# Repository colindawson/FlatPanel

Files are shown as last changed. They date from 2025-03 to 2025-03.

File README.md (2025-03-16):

# Remote FlatPanel to help with taking calibration frames.

This flat panel is going to be an open source, dimmable flat panel for astronomy.

## Features
- Dimmable flat panel
- Optional dew heater
- Flat panel acts like lens cap
- AsiAir remote controlable (both for heater and panel)
- oLed display for local control
- Wifi remote control
- Ascom Alpaca control
- Temperature and humidity sensor
- Fully automatic mode for dew heater

Above is the fully list of features that I'm planning.  Some of the features will cancel out other features. For example Fully Automatic mode will be available for the dew heater, to use the minimum power so that it keeps away dew without human interaction, however I want to have the ability to overrride this in several ways - Using an output from the AsiAir, a dedicated web page, Ascom Alpaca or manually via the display.

The plan is that this is going to be a full solution for any size scope, however, my initial project is based on creating a Panel for my SpaceCat 51 Scope.   Once that is working, I'll be looking at how to modify the project to work with my Meade LX-90.

## Discord

[cjdSkunkWorks/FlatPanel](https://discord.com/channels/800391513091211284/1350925191181631498)

## Todo list
- ~~Upload Display board design prototype~~ (done)
- ~~Upload Mainboard design prototype~~ (done)
- Finish designing 3D files for the SpaceCat51
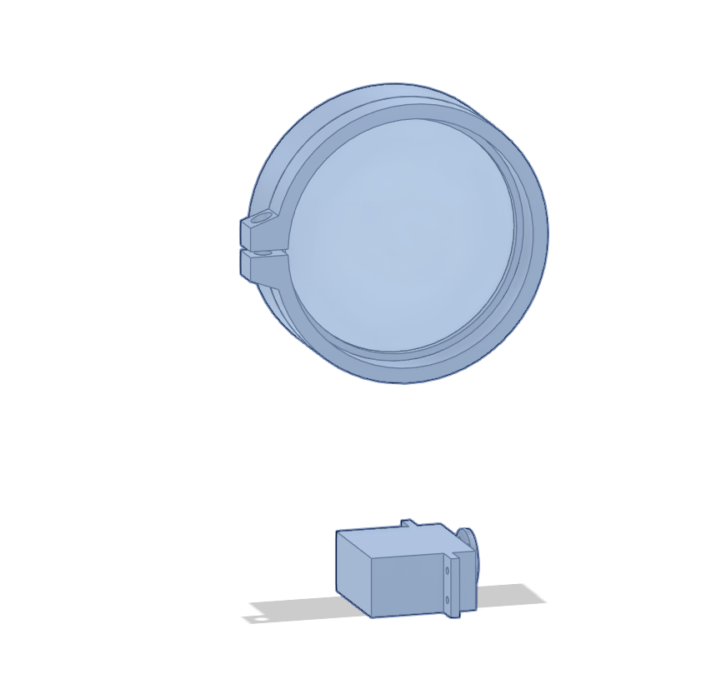
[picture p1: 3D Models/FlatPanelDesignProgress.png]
3D Design Progress
  
- Upload 3d models for the SpaceCat51
- Finalise PCB Layout for Display Board
- Finalise PCB Layout for Mainboard
- Figure out display controls for manual mode
- Create micropython source oode for Pico
- Upgrade MicroPython code to support Pico W, for Web access
- Upgrade MicroPyton code to implement ASCOM Alpaca support

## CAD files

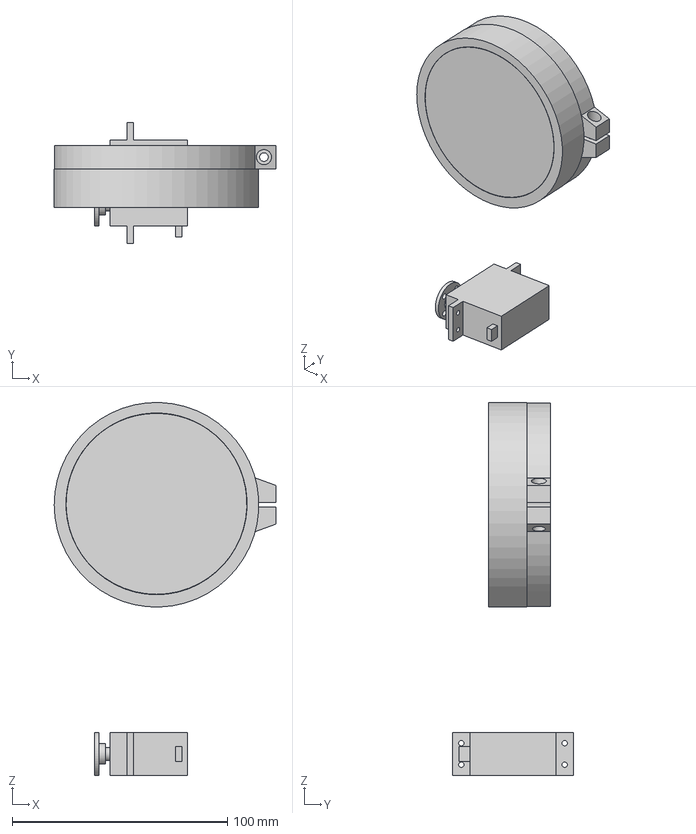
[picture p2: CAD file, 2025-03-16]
3D Models/FlatPanel - SpaceCat51 v10.step
102.9 x 56.4 x 173.2 mm
TelescopeBracket
ServoMockup
FlatPanelHousing

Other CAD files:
3D Models/FlatPanel - SpaceCat51 v10.f3d
3D Models/FlatPanel - SpaceCat51 v10.stl

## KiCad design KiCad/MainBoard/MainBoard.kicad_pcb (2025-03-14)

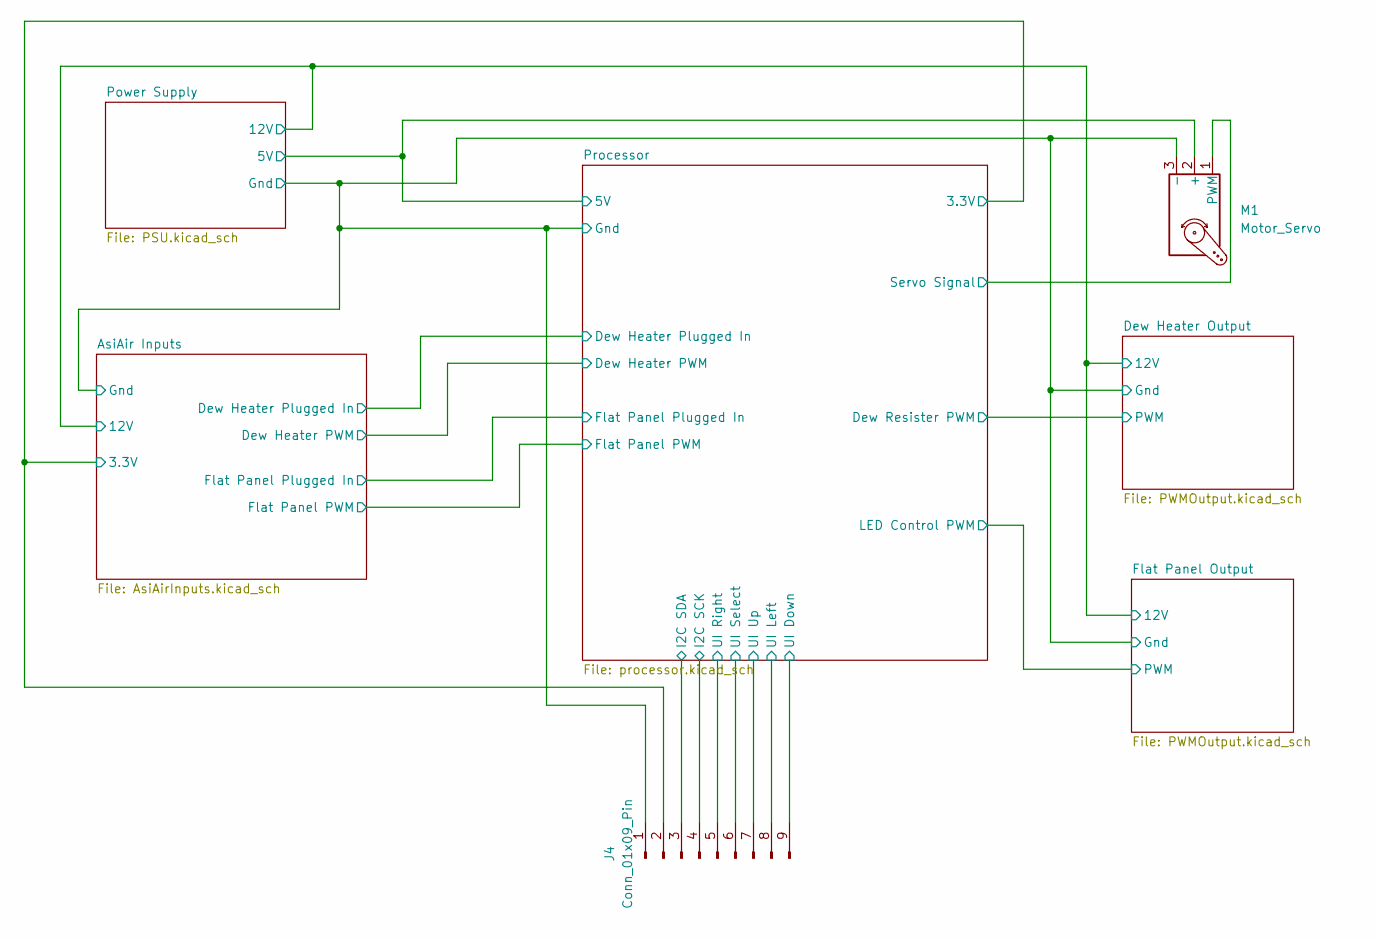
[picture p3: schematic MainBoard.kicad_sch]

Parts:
J4: Conn_01x09_Pin; PinHeader_2x05_P2.54mm_Horizontal
M1: Motor_Servo; PinHeader_1x03_P2.54mm_Vertical

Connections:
/AsiAir Inputs/3.3V: J4.2; also elsewhere on the board
/AsiAir Inputs/Gnd: J4.1, M1.3 (-); also elsewhere on the board
/Power Supply/5V: M1.2 (+); also elsewhere on the board
/Processor/I2C SCK: J4.4; also elsewhere on the board
/Processor/I2C SDA: J4.3; also elsewhere on the board
/Processor/Servo Signal: M1.1 (PWM); also elsewhere on the board
/Processor/UI Down: J4.9; also elsewhere on the board
/Processor/UI Left: J4.8; also elsewhere on the board
/Processor/UI Right: J4.5; also elsewhere on the board
/Processor/UI Select: J4.6; also elsewhere on the board
/Processor/UI Up: J4.7; also elsewhere on the board

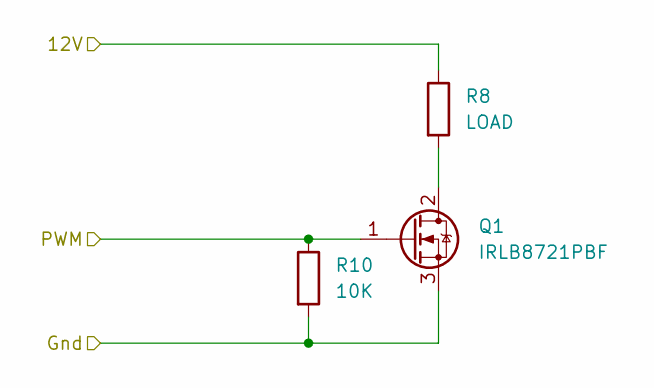
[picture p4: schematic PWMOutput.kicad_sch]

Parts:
Q1: IRLB8721PBF; TO-220-3_Vertical
R8: LOAD; JST_XH_B2B-XH-A_1x02_P2.50mm_Vertical
R10: 10K; R_Axial_DIN0204_L3.6mm_D1.6mm_P5.08mm_Horizontal

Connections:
/AsiAir Inputs/12V: R8.1; also elsewhere on the board
/AsiAir Inputs/Gnd: Q1.3 (S), R10.2; also elsewhere on the board
/Dew Heater Output/PWM: Q1.1 (G), R10.1; also elsewhere on the board
unnamed: Q1.2 (D), R8.2

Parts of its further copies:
Q2: IRLB8721PBF; TO-220-3_Vertical
R9: LOAD; JST_XH_B2B-XH-A_1x02_P2.50mm_Vertical
R11: 10K; R_Axial_DIN0204_L3.6mm_D1.6mm_P5.08mm_Horizontal

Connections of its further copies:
/AsiAir Inputs/12V: R9.1; also elsewhere on the board
/AsiAir Inputs/Gnd: Q2.3 (S), R11.2; also elsewhere on the board
/Flat Panel Output/PWM: Q2.1 (G), R11.1; also elsewhere on the board
unnamed: Q2.2 (D), R9.2

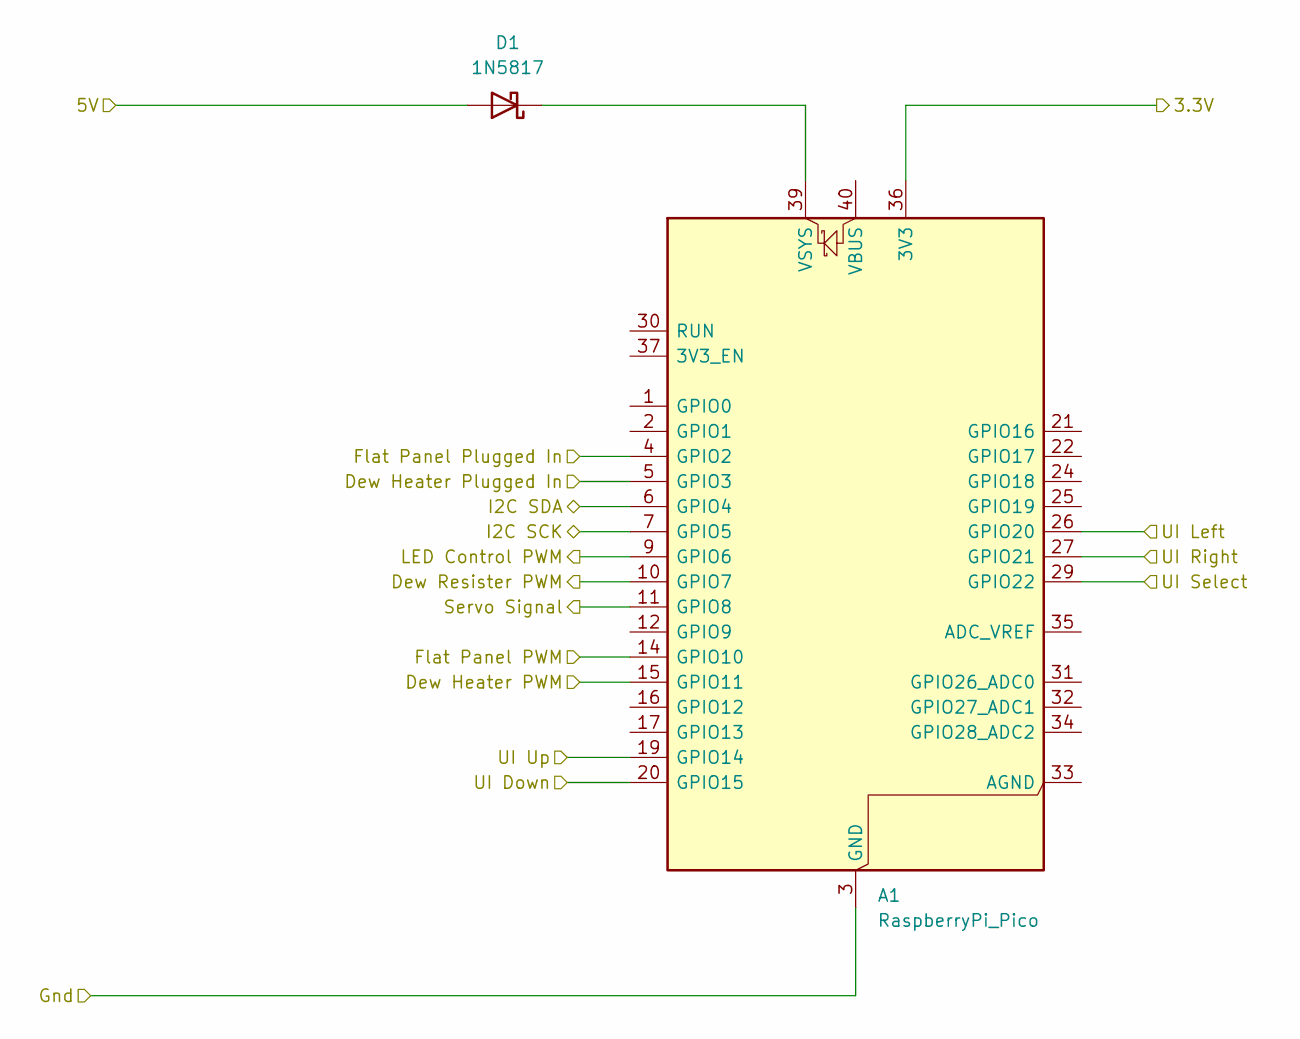
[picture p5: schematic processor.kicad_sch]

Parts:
A1: RaspberryPi_Pico; RaspberryPi_Pico_Common_Unspecified
D1: 1N5817; D_DO-15_P10.16mm_Horizontal

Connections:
/AsiAir Inputs/3.3V: A1.36 (3V3); also elsewhere on the board
/AsiAir Inputs/Dew Heater PWM: A1.15 (GPIO11); also elsewhere on the board
/AsiAir Inputs/Dew Heater Plugged In: A1.5 (GPIO3); also elsewhere on the board
/AsiAir Inputs/Flat Panel PWM: A1.14 (GPIO10); also elsewhere on the board
/AsiAir Inputs/Flat Panel Plugged In: A1.4 (GPIO2); also elsewhere on the board
/AsiAir Inputs/Gnd: A1.3 (GND), A1.8 (GND), A1.13 (GND), A1.18 (GND), A1.23 (GND), A1.28 (GND), A1.38 (GND); also elsewhere on the board
/Dew Heater Output/PWM: A1.10 (GPIO7); also elsewhere on the board
/Flat Panel Output/PWM: A1.9 (GPIO6); also elsewhere on the board
/Power Supply/5V: D1.2 (A); also elsewhere on the board
/Processor/I2C SCK: A1.7 (GPIO5); also elsewhere on the board
/Processor/I2C SDA: A1.6 (GPIO4); also elsewhere on the board
/Processor/Servo Signal: A1.11 (GPIO8); also elsewhere on the board
/Processor/UI Down: A1.20 (GPIO15); also elsewhere on the board
/Processor/UI Left: A1.26 (GPIO20); also elsewhere on the board
/Processor/UI Right: A1.27 (GPIO21); also elsewhere on the board
/Processor/UI Select: A1.29 (GPIO22); also elsewhere on the board
/Processor/UI Up: A1.19 (GPIO14); also elsewhere on the board
unnamed: A1.39 (VSYS), D1.1 (K)

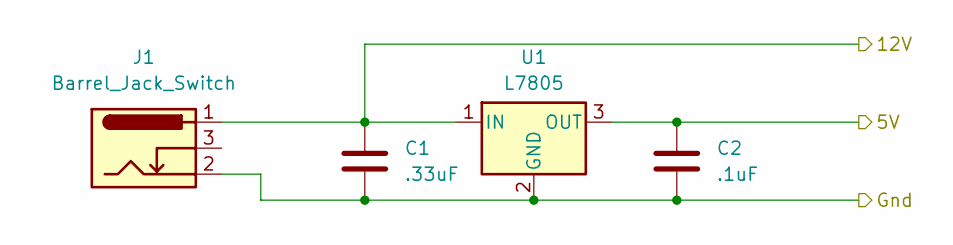
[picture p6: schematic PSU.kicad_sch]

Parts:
C1: .33uF; C_Disc_D5.0mm_W2.5mm_P5.00mm
C2: .1uF; C_Disc_D5.0mm_W2.5mm_P5.00mm
J1: Barrel_Jack_Switch; BarrelJack_Horizontal
U1: L7805; TO-220-3_Vertical

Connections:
/AsiAir Inputs/12V: C1.1, J1.1, U1.1 (IN); also elsewhere on the board
/AsiAir Inputs/Gnd: C1.2, C2.2, J1.2, U1.2 (GND); also elsewhere on the board
/Power Supply/5V: C2.1, U1.3 (OUT); also elsewhere on the board

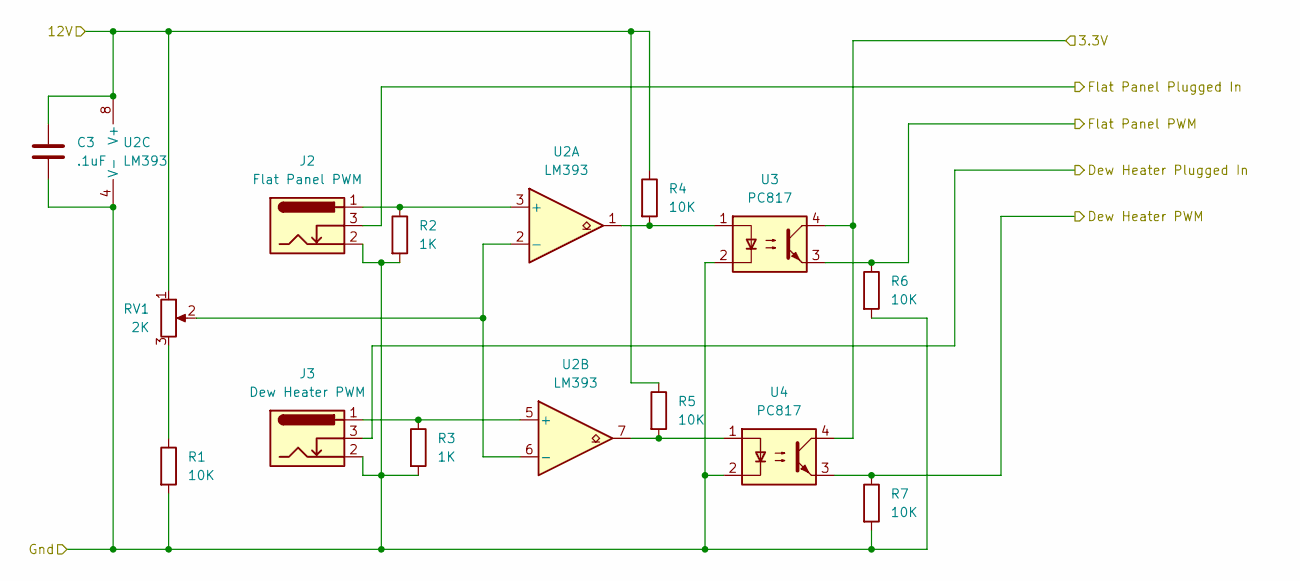
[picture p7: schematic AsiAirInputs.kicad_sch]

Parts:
C3: .1uF; C_Disc_D5.0mm_W2.5mm_P5.00mm
J2: Flat Panel PWM; BarrelJack_Horizontal
J3: Dew Heater PWM; BarrelJack_Horizontal
R1, R4, R5, R6, R7: 10K; R_Axial_DIN0204_L3.6mm_D1.6mm_P5.08mm_Horizontal
R2, R3: 1K; R_Axial_DIN0204_L3.6mm_D1.6mm_P5.08mm_Horizontal
RV1: 2K; Potentiometer_Runtron_RM-065_Vertical
U2: LM393; DIP-8_W7.62mm_Socket
U3, U4: PC817; DIP-4_W7.62mm

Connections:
/AsiAir Inputs/3.3V: U3.4, U4.4; also elsewhere on the board
/AsiAir Inputs/12V: C3.1, R4.1, R5.1, RV1.1, U2.8 (V+); also elsewhere on the board
/AsiAir Inputs/Dew Heater PWM: R7.1, U4.3; also elsewhere on the board
/AsiAir Inputs/Dew Heater Plugged In: J3.3; also elsewhere on the board
/AsiAir Inputs/Flat Panel PWM: R6.1, U3.3; also elsewhere on the board
/AsiAir Inputs/Flat Panel Plugged In: J2.3; also elsewhere on the board
/AsiAir Inputs/Gnd: C3.2, J2.2, J3.2, R1.2, R2.2, R3.2, R6.2, R7.2, U2.4 (V-), U3.2, U4.2; also elsewhere on the board
unnamed: R1.1, RV1.3
unnamed: R4.2, U2.1, U3.1
unnamed: R5.2, U2.7, U4.1
unnamed: J2.1, R2.1, U2.3 (+)
unnamed: RV1.2, U2.2 (-), U2.6 (-)
unnamed: J3.1, R3.1, U2.5 (+)

Board: 2 copper layers, 28 parts (0 on the bottom side), 27 nets, no tracks yet.

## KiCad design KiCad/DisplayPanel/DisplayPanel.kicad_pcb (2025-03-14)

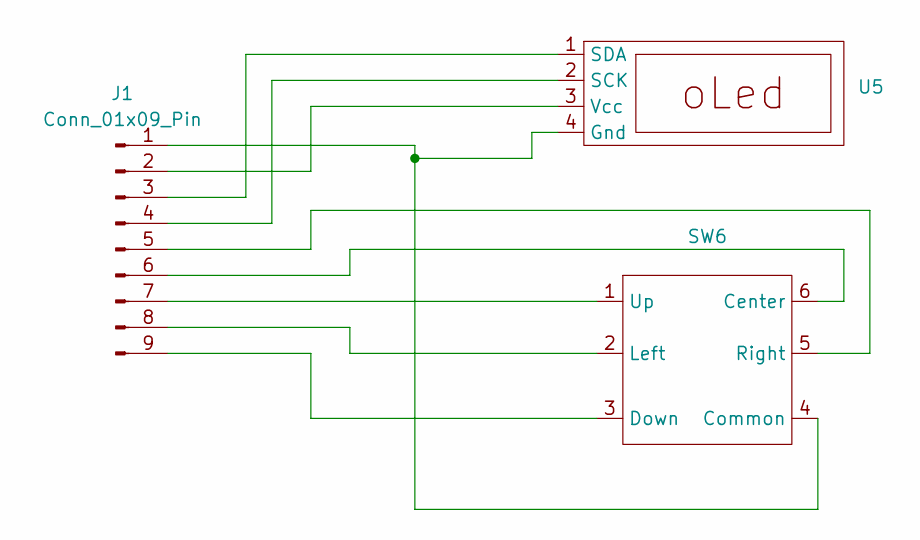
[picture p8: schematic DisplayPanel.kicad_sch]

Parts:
J1: Conn_01x09_Pin; PinHeader_2x05_P2.54mm_Horizontal
SW6: 5WayNavigationSwitch
U5: PinHeader_1x04_P2.54mm_Vertical

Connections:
unnamed: J1.1, SW6.4 (Common), U5.4 (Gnd)
unnamed: J1.2, U5.3 (Vcc)
unnamed: J1.3, U5.1 (SDA)
unnamed: J1.4, U5.2 (SCK)
unnamed: J1.5, SW6.5 (Right)
unnamed: J1.6, SW6.6 (Center)
unnamed: J1.7, SW6.1 (Up)
unnamed: J1.8, SW6.2 (Left)
unnamed: J1.9, SW6.3 (Down)

Board: 2 copper layers, 3 parts (0 on the bottom side), 9 nets, no tracks yet.

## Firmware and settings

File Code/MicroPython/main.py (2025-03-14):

from machine import Pin, PWM, time_pulse_us
from utime import sleep
    
class Servo:
    def __init__(self, pin):
        self.pin = Pin(pin,Pin.OUT)
        self.frequency = 50
        self.minPulseMs = .5
        self.maxPulseMs = 2.5
        self.range = 180
    
    def Start(self):
        self.pwm = PWM(self.pin)
        self.pwm.freq(self.frequency)
    
    def SetPositionPercent(self, percent):
        dutyPercentRangeMs = self.maxPulseMs - self.minPulseMs;
        newDutyMs = self.minPulseMs + ( dutyPercentRangeMs/100 * percent )
        self.pwm.duty_ns(round(newDutyMs * 1000000))
                
    def SetPosition(self,newPos):
        newCyclePercent = (newPos / self.range) * 100
        self.SetPositionPercent(newCyclePercent)
            
    def Stop(self):
        self.pwm.deinit()

class PWMReader:
    def __init__(self, pin, frequency):
        self.pin = Pin(pin,mode=Pin.IN,pull=Pin.PULL_DOWN )
        self.frequencyHZ = frequency
        self.cycleWidthUS = round(1000000/frequency)
        
    def GetPulseWidth(self):
        machine.time_pulse_us(self.pin, 1, self.cycleWidthUS*5)
        return machine.time_pulse_us(self.pin, 1
                                     , self.cycleWidthUS*5)

    def GetDutyCycle(self):
        pulseWidth = self.GetPulseWidth()
        if pulseWidth == -2:
            dutyCycle = 0
        elif pulseWidth == -1:
            dutyCycle = 100
        else:
            dutyCycle=pulseWidth/self.cycleWidthUS * 100
        
        print(dutyCycle, pulseWidth)
        return dutyCycle
        

# Setup PWM Pin for servo control
servo = Servo(0)
pwmReader = PWMReader(15, 50)

servo.Start()
servoPositions = [0,50,100]
try:
        while True:
            for position in servoPositions:
                servo.SetPositionPercent(position)
                dutyCycle = pwmReader.GetDutyCycle()               
                sleep(2)
                #sleep(1)
            
except KeyboardInterrupt:
    print("Keyboard interrupt")
    #Turn off PWM
    servo.Stop()
    

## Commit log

2025-03-14 Adding prototype for the display panel circuit
    [DisplayPanel.kicad_pcb, DisplayPanel.kicad_sch]
2025-03-14 Adding prototype for the Mainboard
    [AsiAirInputs.kicad_sch, MainBoard.kicad_pcb, MainBoard.kicad_sch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]
2025-03-14 Added the current test program for the Pico
2025-03-16 3d Model work in progress
    [FlatPanel - SpaceCat51 v10.f3d, FlatPanel - SpaceCat51 v10.step, FlatPanel - SpaceCat51 v10.stl]
